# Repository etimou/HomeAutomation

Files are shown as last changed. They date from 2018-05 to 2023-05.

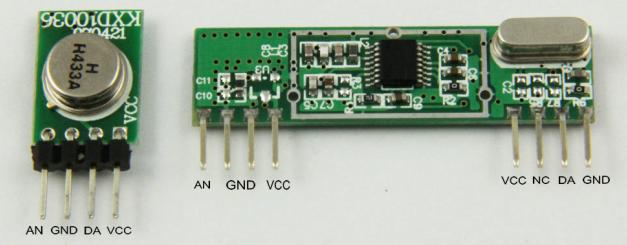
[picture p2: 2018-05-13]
hardware/rfbase/RFmodule_pinout2.jpg

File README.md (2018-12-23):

# HomeAutomation

Installation on Raspberrypi
---------------------------

1. git clone https://github.com/etimou/HomeAutomation
2. sudo apt-get install python-serial lighttpd
3. sudo cp /etc/lighttpd/lighttpd.conf /etc/lighttpd/lighttpd.conf.sav
4. sudo nano /etc/lighttpd/lighttpd.conf
   replace "/var/www/html" by "/home/pi/HomeAutomation/software/raspberrypi/www"
   add "mod_cgi" in the server.modules section

   add
   cgi.assign                 = ( ".pl"  => "/usr/bin/perl",
                               ".cgi" => "/usr/bin/perl",
                               ".rb"  => "/usr/bin/ruby",
                               ".erb" => "/usr/bin/eruby",
                               ".py"  => "/usr/bin/python",
                               ".php" => "/usr/bin/php-cgi" )
  change port from 80 to 8181

5. sudo service lighttpd restart

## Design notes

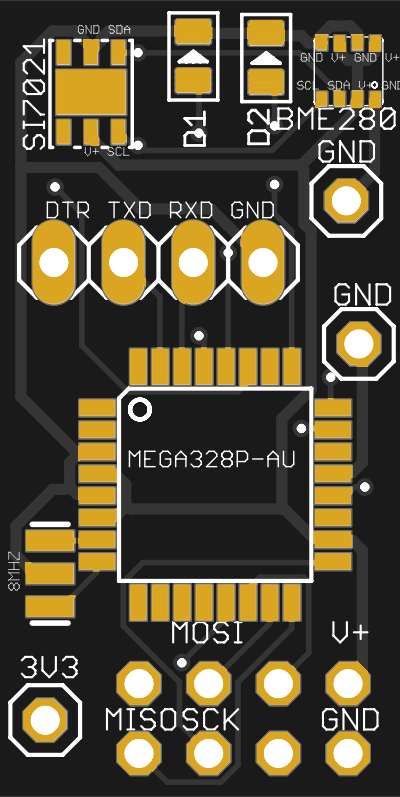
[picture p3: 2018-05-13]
hardware/rfsensor/top.svg.s.png

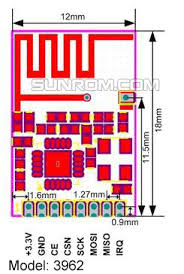
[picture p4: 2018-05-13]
hardware/rfsensor/index.jpeg

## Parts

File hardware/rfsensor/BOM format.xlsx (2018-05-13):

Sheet: PCB Manufacturing Specification
For PCB Manufacturing, would you please tell us the pcb specifications that you want?
You can refer to our webshop:(http://smart-prototyping.com/PCB-Prototyping.html)
Quantity:
Max X-Dimension (cm):
Max Y-Dimension (cm):
Layers:
PCB Thickness (mm):
Copper Thickness:
Surface Finish:
Solder Mask Color:
E-Test Pass:
Solder Paste Stencil:
Separated Sub-Boards:
Lead Time:

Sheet: Please fill in this format
 | BOM quantity (Required) |  | PCB/Project Name
 | Part Identification |  |  |  |  |  |  |  | Customer Information |  | Quantity
# | Part ID / Reference (Required) | Manufacturer | Part / Order Number (Required) | Description | Value (Required) | Package (Required) | THT (y/n) | Pins / Pads | Source/Link/ Datasheet/Note | Source / Target Price | Quantity per BOM (Required)

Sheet: Reference
 | BOM quantity | 10 |  | PCB/Project Name | Main Control V1.0
 | Part Identification |  |  |  |  |  |  |  | Customer Information |  | Quantity
# | Part ID / Reference | Manufacturer | Part / Order Number | Description | Value | Package | THT (y/n) | Pins / Pads | Source/Link/ Datasheet/Note | Source / Target Price | Quantity per BOM
1 | C1, C2, C3, C4, C5, C7, C8, C9, C10, C11, C12, C13, C14, C15, C16, C17 | Samsung | CL10B104KB8NNNC | Capacitor SMD Cer 100nF 10% 50V X7R 0603 | 100nF | 0603 | n | 2 | 478-5052-1-ND |  | 16
2 | C6 | Samsung | CL10A105K08NNNC | Capacitor SMD Cer 1uF 10% 16V X5R 0603 | 1uF | 0603 | n | 1 | 445-1604-1-ND |  | 1
3 | D3, D4, D5 | Kingbright | APT1608SURCK | LED 0603 SMD Hyper Red 630nm 220mcd 20mA | LED_SMD_Red_0603_220mcd |  | n | 2 | 754-1123-1-ND |  | 4
4 | D1 | Lite-On Inc | LTL-4231N | Trigger LED | LED THT |  | y | 2 | 160-1142-ND |  | 1
5 | D4 | Lite-On Inc | LTL-4221N | Power LED | LED THT |  | y | 2 | 160-1139-ND |  | 1
6 | D2 | Kingbright | APT1608CGCK | LED 0603 SMD Green 570nm 50mcd 20mA | LED_SMD_Green_0603_570nm |  | n | 2 | 754-1116-1-ND |  | 1
7 | D5 | ON Semiconductor | BAT54T1G | Schottky Barrier Diode, 2-Pin SOD-123, Tape and Reel | BAT54T1 |  | n | 2 | BAT54T1GOSCT-ND |  | 1
8 | D6 | Micro Commercial Co | BZT52C5V1-TP | Diode Zener SMD 5.1V 0.5W SOD-123 | DIODE_ZENER_4.7V_500mW |  | n | 2 | BZT52C5V1-TPMSCT-ND |  | 1
9 | H1 |  |  | Male Header, 2-Pin, straight, 2.54mm pitch | Header 2 |  | y | 2 | 455-1749-1-ND |  | 1
10 | ICSP1, J4 |  |  | Male Header, 3-Pin, Dual row, straight, 2.54mm pitch | Header 3X2 |  | y | 6 | 952-2092-ND |  | 2
11 | J1, J3, J5 | CUI Inc | SJ-2524-SMT-TR | 2.5mm Audio jack | SJ-2524-SMT |  | n | 4 | CP-2524SJTR-ND |  | 3
12 | J2 | JAE Electronics | DX4R005HJ5R2000 | Connector SMD USB Micro Type B middle mount | USB_Micro_TypeB |  | n | 9 | 670-2674-1-ND |  | 1

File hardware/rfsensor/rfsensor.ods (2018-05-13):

Id | Designator | Package | Quantity | Designation | Supplier and ref
1 | J4 |  | not mounted
2 | C1 | C_0603 | 1 | 10nF
3 | C2,C4,C5,C6 | C_0603 | 4 | 0.1uF
4 | C3,C7 | SMD-1206_Pol | 2 | 10uF
5 | D1 | LED_0603 | 1 | Green
6 |  |  | not mounted
7 |  |  | not mounted
8 | JP1 | Pin_Header_Straight_1x06_Pitch2.54mm | not mounted | CONN_01X06
9 | Q1 | Resonator_smd | 1 | 8MHz Ceramic Resonator Built in Capacitor Surface Mount | Murata Electronics North America
10 | R1 | R_0603 | 1 | 1M
11 | R2 | R_0603 | 1 | 330
12 | R3 | R_0603 | 1 | 10k
13 | R4,R5 | R_0603 | 2 | R
14 |  |  | not mounted
15 | U2 | TQFP-32_7x7mm_Pitch0.8mm | 1 | ATMEGA328P-AU | Microchip Technology
16 | U1 | si7021 | 1 | Si7021-A20 | SILICON LABS
17 | J5 |  | not mounted

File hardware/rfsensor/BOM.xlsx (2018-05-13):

 | Repere topographique | Quantite | Description | Fabricant | Reference (fabricant) | SKU (référence RS / Farnell / DigiKey / Mouser) | Fournisseur (RS / FA / DK / MO)
Exemple 1 : | C1,C2,C4,C5,C6 | 5 |  |  | C0603C104M4RACTU
 | U2 |  |  |  | ATMEGA328P-AUR
 | Q1 |  |  |  | CSTCE8M00G55-R0 |  | FA
 | Mode d'emploi : | Bien lire avant …..
 | L'ordre des colonnes n'a pas d'importance, seul les titres ont une importance
 | Les titres de colonne doivent être conservés (Repere, Quantite, Description, Fabricant, Reference, SKU)
 | La liste de composants doit commencer sur la deuxième ligne (Ligne '2')
 | Les répère topographique doivent être séparés par des virgules et/ou espace ; Attention, le système ne contrôle pas les doublons sur les repères topographiques
 | La quantité doit correspondre au nombre de repères topographiques
 | Si une description est nécessaire, il faut séparer ses caractéristiques par des espaces
 | La référence est prioritaire sur la description et ne doit contenir aucun espace (mais vous pouvez quand même renseigner la description, cela vous aidera à vérifier la recherche)
 | Le SKU est prioritaire sur la description et la référence fabricant (mais vous pouvez quand même renseigner ces informations, cela vous aidera à vérifier la recherche)
 | Un SKU doit être accompagné du fournisseur (RS / FA / DK / MO)
 | ATTENTION:
 | les informations "Référence / SKU" peuvent être informés en "ET / OU"
 | Par contre, si vous informez "SKU" qui est prioritaire, en fonction de la référence du fournisseur choisi (dispo ou pas), les 3 autres distributeurs ne seront pas consultés.
 | Pour une recherche élargie, nous vous conseillons d'indiquer seulement la référence

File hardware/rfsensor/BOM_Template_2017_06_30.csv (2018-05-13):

Designator | Manufacturer Part Number | Quantity
C1,C2,C3,C4,C5 | RHA0J471MCN1GS | 5
A1,A4 | 318020010 | 2
D1 | CYBLE-014008-00 | 1

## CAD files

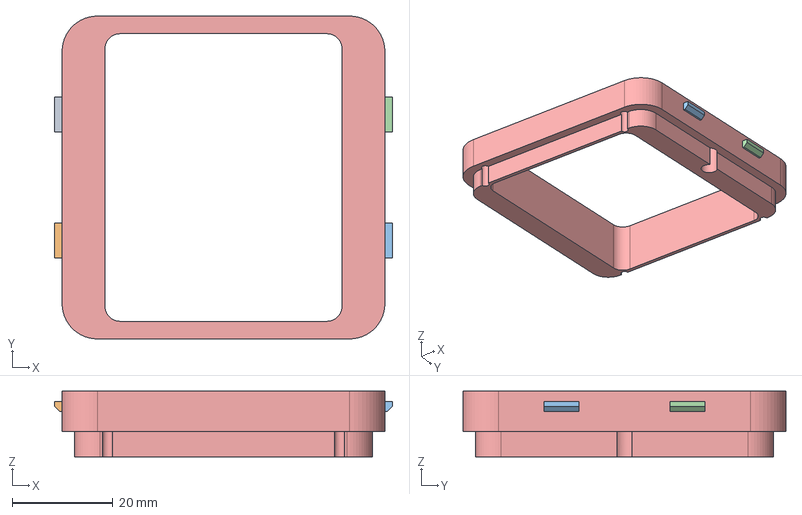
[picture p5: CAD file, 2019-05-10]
hardware/keypad/keypad3.fcstd
67.0 x 64.0 x 13.0 mm

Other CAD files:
hardware/rfsensor/gerber/rfsensor-F.Paste.dxf

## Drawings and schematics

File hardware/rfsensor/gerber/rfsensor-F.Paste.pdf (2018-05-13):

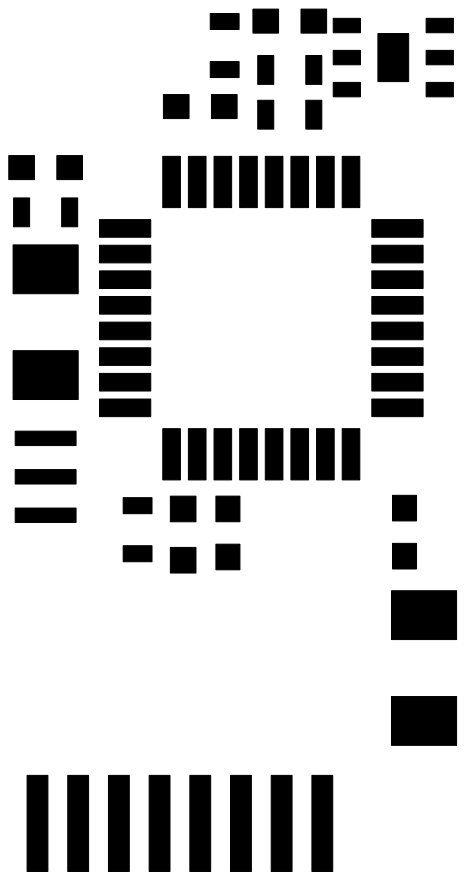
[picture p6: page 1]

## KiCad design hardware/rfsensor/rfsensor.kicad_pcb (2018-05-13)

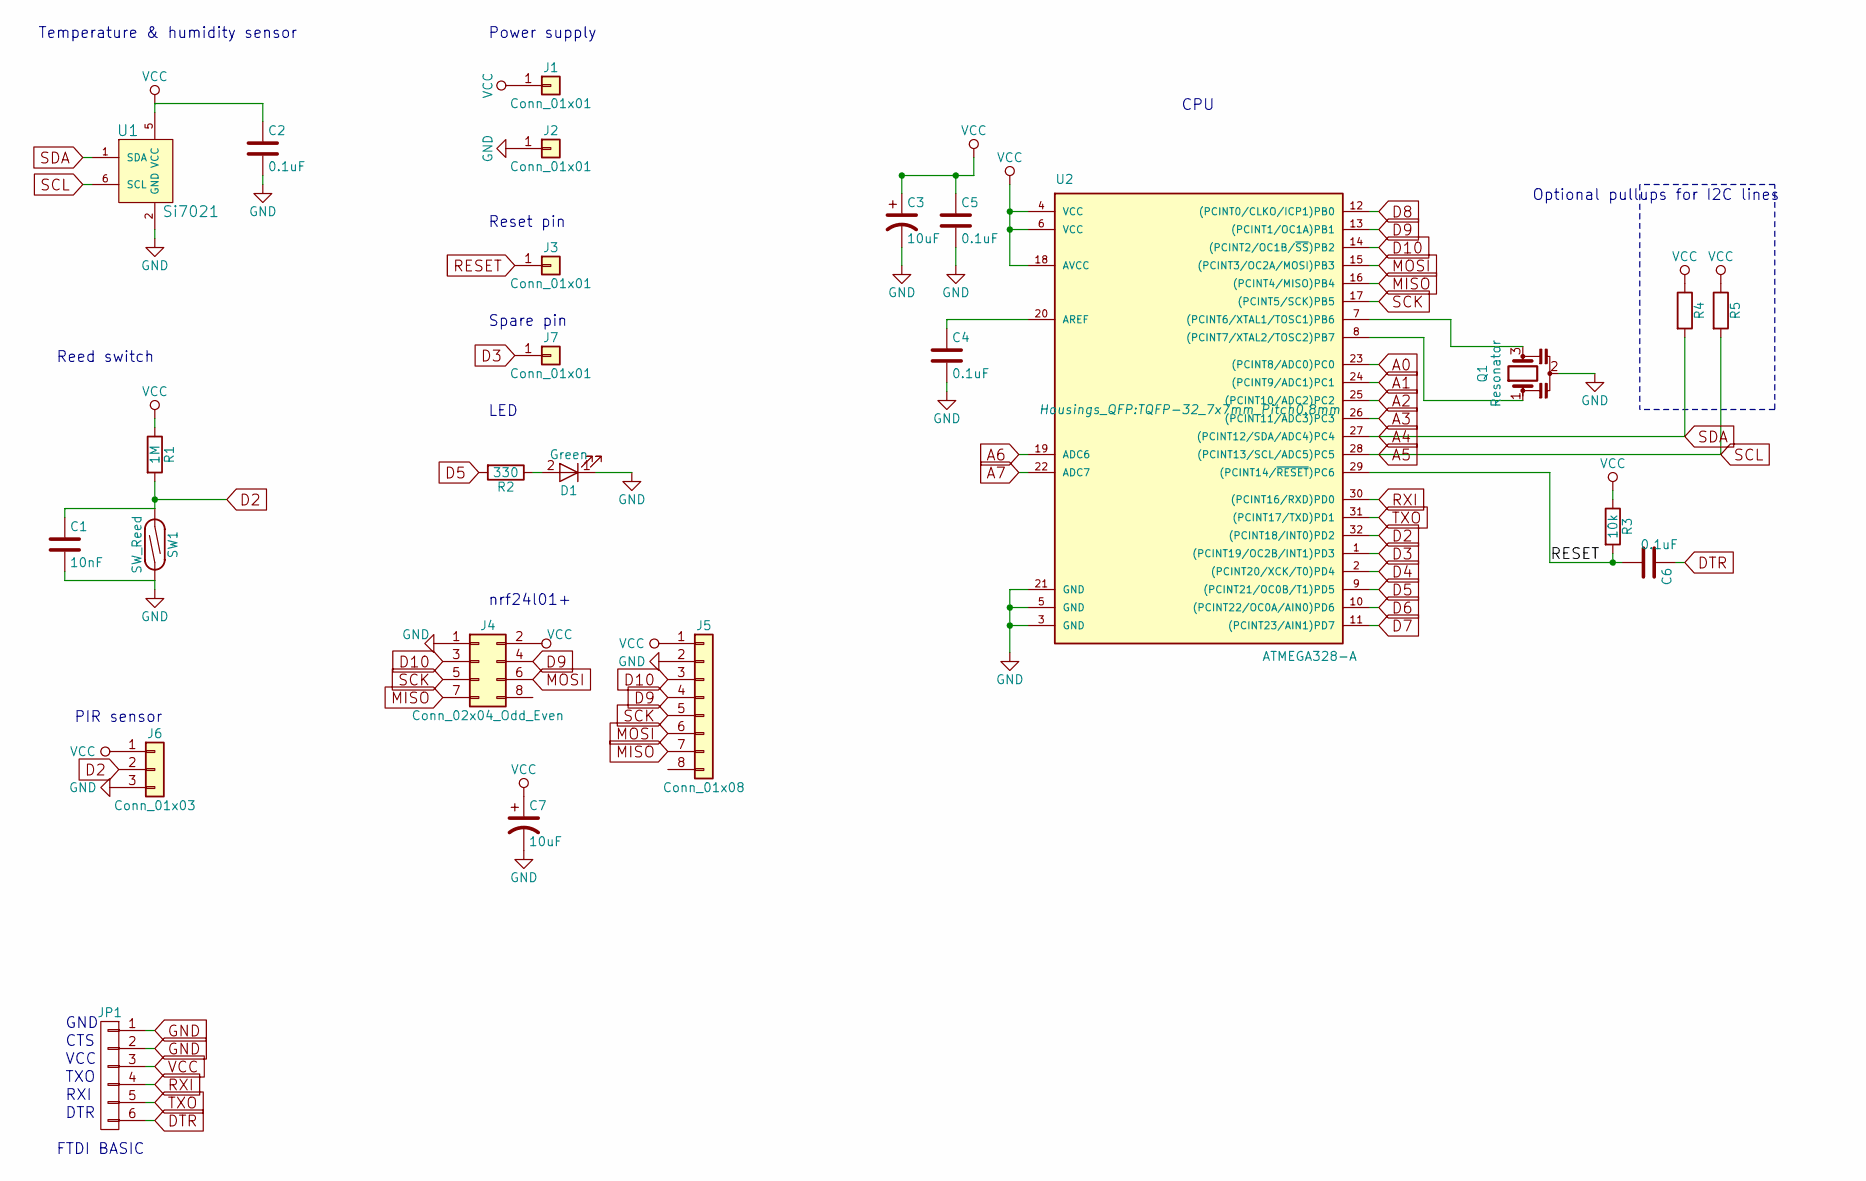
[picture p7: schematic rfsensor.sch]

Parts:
C1: 10nF; C_0603
C2, C4, C5, C6: 0.1uF; C_0603
C3, C7: 10uF; SMD-1206_Pol
D1: Green; LED_0603
J1, J2, J3, J7: Conn_01x01; Pin_Header_Straight_1x01_Pitch2.54mm
J4: Conn_02x04_Odd_Even; Pin_Header_Straight_2x04_Pitch2.54mm
J5: Conn_01x08; Pin_Header_Straight_1x08_Pitch1.27mm_SMD_Pin1Left
J6: Conn_01x03; Pin_Header_Straight_1x03_Pitch2.54mm
JP1: CONN_01X06; Pin_Header_Straight_1x06_Pitch2.54mm
Q1: Resonator; Resonator_smd
R1: 1M; R_0603
R2: 330; R_0603
R3: 10k; R_0603
R4, R5: R; R_0603
SW1: SW_Reed; reed
U1: Si7021; DFN-6-1EP_3x3mm_Pitch0.95mm
U2: ATMEGA328-A; TQFP-32_7x7mm_Pitch0.8mm

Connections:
A0: U2.23 ((PCINT8/ADC0)PC0)
A1: U2.24 ((PCINT9/ADC1)PC1)
A2: U2.25 ((PCINT10/ADC2)PC2)
A3: U2.26 ((PCINT11/ADC3)PC3)
A4: R4.2, U1.1 (SDA), U2.27 ((PCINT12/SDA/ADC4)PC4)
A5: R5.2, U1.6 (SCL), U2.28 ((PCINT13/SCL/ADC5)PC5)
A6: U2.19 (ADC6)
A7: U2.22 (ADC7)
D2: C1.1, J6.2, R1.2, SW1.1, U2.32 ((PCINT18/INT0)PD2)
D3: J7.1, U2.1 ((PCINT19/OC2B/INT1)PD3)
D4: U2.2 ((PCINT20/XCK/T0)PD4)
D5: R2.2, U2.9 ((PCINT21/OC0B/T1)PD5)
D6: U2.10 ((PCINT22/OC0A/AIN0)PD6)
D7: U2.11 ((PCINT23/AIN1)PD7)
D8: U2.12 ((PCINT0/CLKO/ICP1)PB0)
D9: J4.4, J5.4, U2.13 ((PCINT1/OC1A)PB1)
D10: J4.3, J5.3, U2.14 ((PCINT2/OC1B/~SS~)PB2)
DTR: C6.1, JP1.6
GND: C1.2, C2.2, C3.2, C4.2, C5.2, C7.2, D1.1 (K), J2.1, J4.1, J5.2, J6.3, JP1.1, JP1.2, Q1.2, SW1.2, U1.2 (GND), U2.3 (GND), U2.5 (GND), U2.21 (GND)
MISO: J4.7, J5.7, U2.16 ((PCINT4/MISO)PB4)
MOSI: J4.6, J5.6, U2.15 ((PCINT3/OC2A/MOSI)PB3)
unnamed: C4.1, U2.20 (AREF)
unnamed: D1.2 (A), R2.1
unnamed: Q1.1, U2.8 ((PCINT7/XTAL2/TOSC2)PB7)
unnamed: Q1.3, U2.7 ((PCINT6/XTAL1/TOSC1)PB6)
RESET: C6.2, J3.1, R3.2, U2.29 ((PCINT14/~RESET~)PC6)
RXI: JP1.4, U2.30 ((PCINT16/RXD)PD0)
SCK: J4.5, J5.5, U2.17 ((PCINT5/SCK)PB5)
TXO: JP1.5, U2.31 ((PCINT17/TXD)PD1)
VCC: C2.1, C3.1, C5.1, C7.1, J1.1, J4.2, J5.1, J6.1, JP1.3, R1.1, R3.1, R4.1, R5.1, U1.5 (VCC), U2.4 (VCC), U2.6 (VCC), U2.18 (AVCC)

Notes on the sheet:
Optional pullups for I2C lines
GND
CTS
VCC
TXO
RXI
DTR
FTDI BASIC
nrf24l01+
Power supply
Reset pin
Temperature & humidity sensor
Reed switch
CPU
LED
PIR sensor
Spare pin

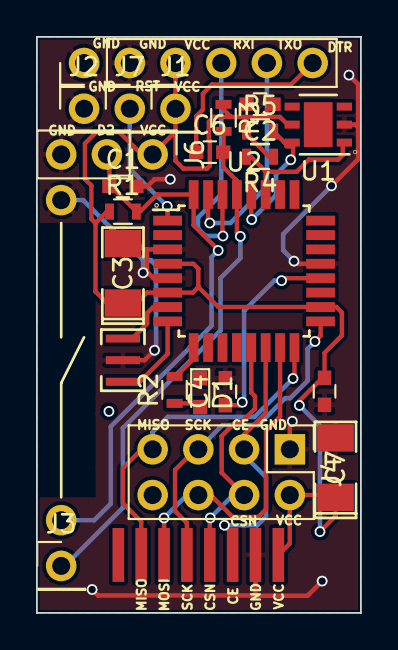
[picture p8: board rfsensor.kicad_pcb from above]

Board: 2 copper layers, 18.0 x 32.0 mm, 25 parts (0 on the bottom side), 20 nets.

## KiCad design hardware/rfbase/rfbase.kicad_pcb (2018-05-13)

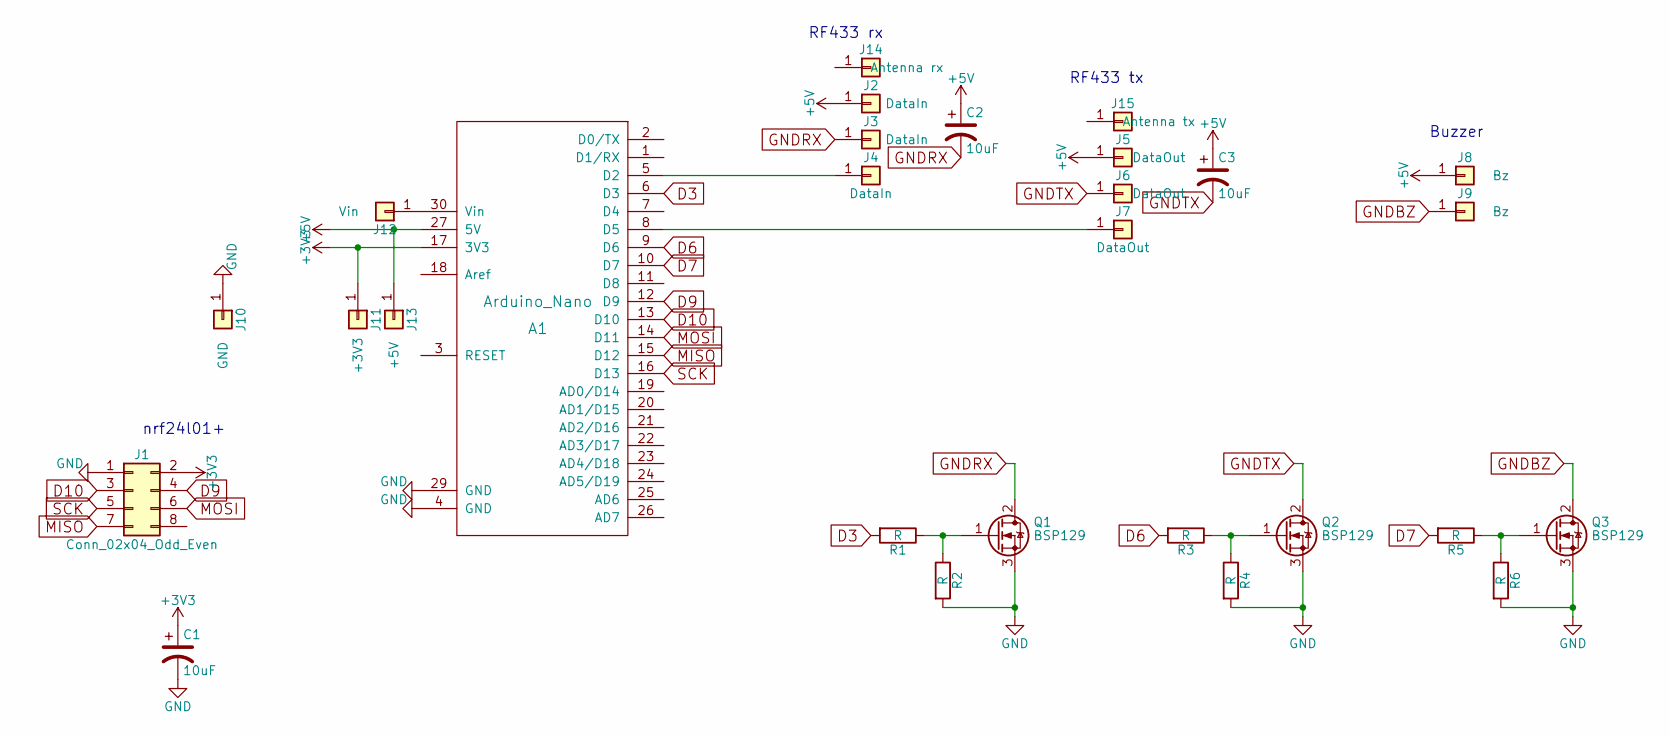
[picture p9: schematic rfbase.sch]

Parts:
A1: Arduino_Nano; arduino_nano
C1, C2, C3: 10uF; SMD-1206_Pol
J1: Conn_02x04_Odd_Even; Pin_Header_Straight_2x04_Pitch2.54mm
J2, J3, J4: DataIn; Pin_Header_Straight_1x01_Pitch2.54mm
J5, J6, J7: DataOut; Pin_Header_Straight_1x01_Pitch2.54mm
J8, J9: Bz; Pin_Header_Straight_1x01_Pitch2.54mm
J10: GND; Pin_Header_Straight_1x01_Pitch2.54mm
J11: +3V3; Pin_Header_Straight_1x01_Pitch2.54mm
J12: Vin; Pin_Header_Straight_1x01_Pitch2.54mm
J13: +5V; Pin_Header_Straight_1x01_Pitch2.54mm
J14: Antenna rx; Pin_Header_Straight_1x01_Pitch2.54mm
J15: Antenna tx; Pin_Header_Straight_1x01_Pitch2.54mm
Q1, Q2, Q3: BSP129; SOT-223-3Lead_TabPin2
R1, R2, R3, R4, R5, R6: R; R_0603

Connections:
+3V3: A1.17 (3V3), C1.1, J1.2, J11.1
+5V: A1.27 (5V), C2.1, C3.1, J2.1, J5.1, J8.1, J13.1
D3: A1.6 (D3), R1.2
D6: A1.9 (D6), R3.2
D7: A1.10 (D7), R5.2
D9: A1.12 (D9), J1.4
D10: A1.13 (D10), J1.3
GND: A1.4 (GND), A1.29 (GND), C1.2, J1.1, J10.1, Q1.3 (S), Q2.3 (S), Q3.3 (S), R2.2, R4.2, R6.2
GNDBZ: J9.1, Q3.2 (D)
GNDRX: C2.2, J3.1, Q1.2 (D)
GNDTX: C3.2, J6.1, Q2.2 (D)
MISO: A1.15 (D12), J1.7
MOSI: A1.14 (D11), J1.6
unnamed: A1.5 (D2), J4.1
unnamed: A1.8 (D5), J7.1
unnamed: A1.30 (Vin), J12.1
unnamed: Q1.1 (G), R1.1, R2.1
unnamed: Q2.1 (G), R3.1, R4.1
unnamed: Q3.1 (G), R5.1, R6.1
SCK: A1.16 (D13), J1.5

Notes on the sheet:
nrf24l01+
RF433 rx
RF433 tx
Buzzer

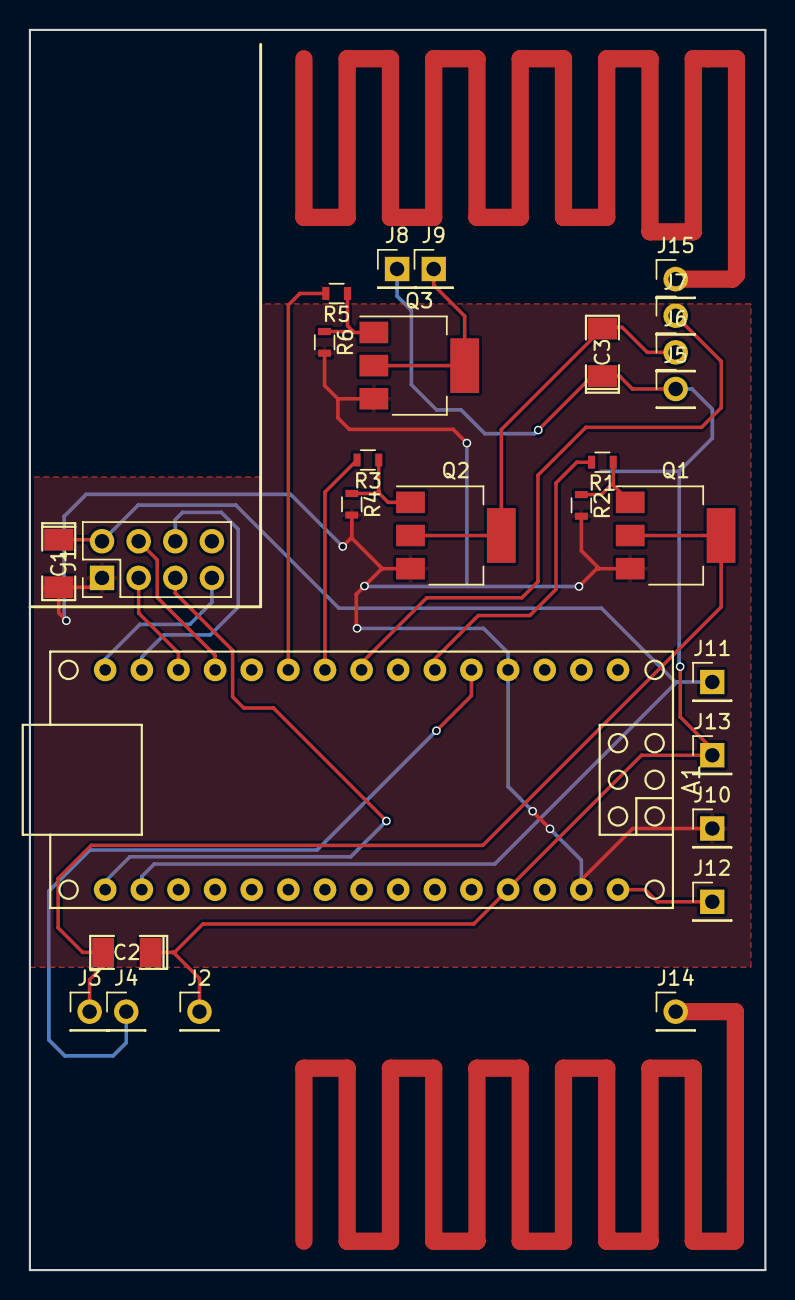
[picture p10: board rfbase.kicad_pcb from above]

Board: 2 copper layers, 51.0 x 86.0 mm, 28 parts (0 on the bottom side), 20 nets.

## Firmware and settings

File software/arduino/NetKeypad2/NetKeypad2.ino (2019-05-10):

// Wake from deep sleep with a keypress demonstration

// Author: Nick Gammon
// Date: 18th November 2012

#include "Keypad2.h"
#include <avr/sleep.h>
#include <avr/power.h>
#include <SPI.h>
#include <RF24.h>
#include <EEPROM.h>

const byte ROWS = 4;
const byte COLS = 3; 

char keys[ROWS][COLS] = 
  {
    {'1', '2', '3'},
    {'4', '5', '6'},
    {'7', '8', '9'},
    {'*', '0', '#'},
  };

byte rowPins[ROWS] = {6, 7, 8, 9}; //connect to the row pinouts of the keypad
byte colPins[COLS] = {2, 3, 4}; //connect to the column pinouts of the keypad
bool state;

/*
arduino keypad 
6 2
7 7
8 6
9 4

2 3
3 1
4 5
*/


/*                           NRF24L01      
 * NC----------------------IRQ 8 7 MISO---------------12
 * 11---------------------MOSI 6 5 SCK----------------13
 *  5-----------------------CS 4 3 CE-----------------10
 *VCC----------------------VCC 2 1 GND----------------GND
 */

char secretCodeON[4] = {'7', '5', '1', '#'};
char secretCodeOFF[4] = {'7', '5', '0', '#'};
char enteredCode[4] = {'0', '0', '0', '0'};
  
// number of items in an array
#define NUMITEMS(arg) ((unsigned int) (sizeof (arg) / sizeof (arg [0])))

const byte ledPin = A0;
unsigned long calib=0;
byte sensorID=0;
byte voltage=0;

  // Create the Keypad
Keypad kpd = Keypad( makeKeymap(keys), rowPins, colPins, ROWS, COLS );


/* Set up nRF24L01 radio on SPI bus plus pins 10 & 9 */
RF24 radio(10,5);
byte addresses[6] = "1Node";

/*

Pin change interrupts.

Pin                  Mask / Flag / Enable

D0    PCINT16 (PCMSK2 / PCIF2 / PCIE2)
D1    PCINT17 (PCMSK2 / PCIF2 / PCIE2)
D2    PCINT18 (PCMSK2 / PCIF2 / PCIE2)
D3    PCINT19 (PCMSK2 / PCIF2 / PCIE2)
D4    PCINT20 (PCMSK2 / PCIF2 / PCIE2)
D5    PCINT21 (PCMSK2 / PCIF2 / PCIE2)
D6    PCINT22 (PCMSK2 / PCIF2 / PCIE2)
D7    PCINT23 (PCMSK2 / PCIF2 / PCIE2)
D8    PCINT0 (PCMSK0 / PCIF0 / PCIE0)
D9    PCINT1 (PCMSK0 / PCIF0 / PCIE0)
D10   PCINT2 (PCMSK0 / PCIF0 / PCIE0)
D11   PCINT3 (PCMSK0 / PCIF0 / PCIE0)
D12   PCINT4 (PCMSK0 / PCIF0 / PCIE0)
D13   PCINT5 (PCMSK0 / PCIF0 / PCIE0)
A0    PCINT8 (PCMSK1 / PCIF1 / PCIE1)
A1    PCINT9 (PCMSK1 / PCIF1 / PCIE1)
A2    PCINT10 (PCMSK1 / PCIF1 / PCIE1)
A3    PCINT11 (PCMSK1 / PCIF1 / PCIE1)
A4    PCINT12 (PCMSK1 / PCIF1 / PCIE1)
A5    PCINT13 (PCMSK1 / PCIF1 / PCIE1)

*/

// turn off interrupts until we are ready
ISR (PCINT0_vect)
  {
  PCICR = 0;  // cancel pin change interrupts
  } // end of ISR (PCINT0_vect)

ISR (PCINT1_vect)
  {
  PCICR = 0;  // cancel pin change interrupts
  } // end of ISR (PCINT1_vect)

ISR (PCINT2_vect)
  {
  PCICR = 0;  // cancel pin change interrupts
  } // end of ISR (PCINT2_vect)

byte readVcc() {
  // Read 1.1V reference against AVcc
  // set the reference to Vcc and the measurement to the internal 1.1V reference
  #if defined(__AVR_ATmega32U4__) || defined(__AVR_ATmega1280__) || defined(__AVR_ATmega2560__)
    ADMUX = _BV(REFS0) | _BV(MUX4) | _BV(MUX3) | _BV(MUX2) | _BV(MUX1);
  #elif defined (__AVR_ATtiny24__) || defined(__AVR_ATtiny44__) || defined(__AVR_ATtiny84__)
    ADMUX = _BV(MUX5) | _BV(MUX0);
  #elif defined (__AVR_ATtiny25__) || defined(__AVR_ATtiny45__) || defined(__AVR_ATtiny85__)
    ADMUX = _BV(MUX3) | _BV(MUX2);
  #else
    ADMUX = _BV(REFS0) | _BV(MUX3) | _BV(MUX2) | _BV(MUX1);
  #endif  

  delay(70); // Wait for Vref to settle
  ADCSRA |= _BV(ADSC); // Start conversion
  while (bit_is_set(ADCSRA,ADSC)); // measuring

  uint8_t low  = ADCL; // must read ADCL first - it then locks ADCH  
  uint8_t high = ADCH; // unlocks both

  long result = (high<<8) | low;

  result = calib / result; // Calculate Vcc (in mV); 1125300 = 1.1*1023*1000 //ok for proto w/ intermediate PCB
  
  //from millivolt to percentage
  result=map(result, 3000, 3400, 0, 100); //3.0V->0% 3.4V->100%

  if (result >100) return 100;
  if (result <0) return 0;
  return (byte)result; // Vcc in millivolts

/*
While the large tolerance of the internal 1.1 volt reference greatly limits the accuracy of 
this measurement, for individual projects we can compensate for greater accuracy. To do so, 
simply measure your Vcc with a voltmeter and with our readVcc() function. Then, replace the 
constant 1125300L with a new constant:
scale_constant = internal1.1Ref * 1023 * 1000
where
internal1.1Ref = 1.1 * Vcc1 (per voltmeter) / Vcc2 (per readVcc() function)
This calibrated value will be good for the AVR chip measured only, and may be subject to temperature variation. Feel free to experiment with your own measurements.
*/
}

void radioSetup(){
  radio.begin();

  // Set the PA Level low to prevent power supply related issues since this is a
  // getting_started sketch, and the likelihood of close proximity of the devices. RF24_PA_MAX is default.
  //radio.setPALevel(RF24_PA_LOW);
  
  radio.setPALevel(RF24_PA_MAX);
  radio.setDataRate(RF24_250KBPS);
  radio.setChannel(108);
  //radio.setRetries(5,15);
  radio.setPayloadSize(4);
  
  // Open a writing and reading pipe on each radio, with opposite addresses
  radio.openWritingPipe(addresses);
  radio.stopListening();
  radio.powerDown();
}
void sendRadioData(){
    //Power up the radio
    radio.powerUp();
  
    byte data_to_send[4];
    data_to_send[0]= sensorID;
    data_to_send[1]= state;
    data_to_send[2]= voltage;
    data_to_send[3]= 0;

    radio.write( data_to_send, 4);

    //Power off the radio    
    radio.powerDown();
  
}

void setup ()
{
  pinMode (ledPin, OUTPUT);

  //radio setup
  radioSetup();

  // pin change interrupt masks (see above list)
  PCMSK2 |= bit (PCINT22);   // pin 6
  PCMSK2 |= bit (PCINT23);   // pin 7
  PCMSK0 |= bit (PCINT0);    // pin 8
  PCMSK0 |= bit (PCINT1);    // pin 9



  Serial.begin(57600);
  // get the device ID from EEPROM address 0
  //EEPROM.write(0, 12);
  sensorID = EEPROM.read(0);
  Serial.print("Device ID=");
  Serial.println(sensorID);

  //get the calibration value
  //EEPROM.put(1,1108835L);
  EEPROM.get(1, calib);
  Serial.print("Calibration value=");
  Serial.println(calib);

  Serial.println("Initialisation complete.");

  // calibration and Id
  char readchar[5];
  char nchar=0;
  while (millis()<5000){
    while (Serial.available()>0){
      if (nchar<=4){
        readchar[nchar]=Serial.read();
        nchar++;
      }
      if (nchar==5){
        if (readchar[0]=='s' && readchar[3]=='c'){
          char newID = (readchar[1]-48)*10+readchar[2]-48;
          if (newID){
            saveIdToEEPROM((readchar[1]-48)*10+readchar[2]-48);
          }
          if ((readchar[4]-48)==1){
            calibrationVoltage(3300);
          }
        }
        else{
          Serial.print("Wrong command...");
        }
        Serial.println("Starting main program");

        delay(50);
        while (Serial.available()>0){Serial.read();}
        
        return;
      }
    } 
  }
  Serial.println("No command received... Starting main program");
  Serial.end();

  delay(100);


}  // end of setup

// set pins as keypad library expects them
// or call: kpd.initializePins ();
//    however in the library I have that is a private method

void reconfigurePins ()
  {
  byte i;
  
  // go back to all pins as per the keypad library
  
  for (i = 0; i < NUMITEMS (colPins); i++)
    {
    pinMode (colPins [i], OUTPUT);
    digitalWrite (colPins [i], HIGH); 
    }  // end of for each column 

  for (i = 0; i < NUMITEMS (rowPins); i++)
    {
    pinMode (rowPins [i], INPUT_PULLUP);
    }   // end of for each row

  }  // end of reconfigurePins

void goToSleep ()
  {
  byte i;
   
  // set up to detect a keypress
  for (i = 0; i < NUMITEMS (colPins); i++)
    {
    pinMode (colPins [i], OUTPUT);
    digitalWrite (colPins [i], LOW);   // columns low
    }  // end of for each column

  for (i = 0; i < NUMITEMS (rowPins); i++)
    {
    pinMode (rowPins [i], INPUT_PULLUP);
    }  // end of for each row
    
   // now check no pins pressed (otherwise we wake on a key release)
   for (i = 0; i < NUMITEMS (rowPins); i++)
    {
    if (digitalRead (rowPins [i]) == LOW)
       {
       reconfigurePins ();
       return; 
       } // end of a pin pressed
    }  // end of for each row
  
  // overcome any debounce delays built into the keypad library
  delay (50);
  
  // at this point, pressing a key should connect the high in the row to the 
  // to the low in the column and trigger a pin change
  
  set_sleep_mode (SLEEP_MODE_PWR_DOWN);  
  sleep_enable();

  byte old_ADCSRA = ADCSRA;
  // disable ADC to save power
  ADCSRA = 0;  

  power_all_disable ();  // turn off various modules
   
  PCIFR  |= bit (PCIF0) | bit (PCIF1) | bit (PCIF2);   // clear any outstanding interrupts
  PCICR  |= bit (PCIE0) | bit (PCIE1) | bit (PCIE2);   // enable pin change interrupts
   
  // turn off brown-out enable in software
  MCUCR = bit (BODS) | bit (BODSE);
  MCUCR = bit (BODS); 
  sleep_cpu ();  
 
  // cancel sleep as a precaution
  sleep_disable();
  power_all_enable ();   // enable modules again
  ADCSRA = old_ADCSRA;   // re-enable ADC conversion
  
  // put keypad pins back how they are expected to be
  reconfigurePins ();
    
  }  // end of goToSleep
  
void loop () 
  {
   
   byte key =  kpd.getKey();
   if (!key)
     {
     // no key pressed? go to sleep
     goToSleep ();
     return;
     }


  // confirmation we woke - flash LED number of times
  // for the appropriate pin (eg. pin 1: one time) 
  /*
  for (byte i = 0; i < (key - '0'); i++)
    {
    digitalWrite (ledPin, HIGH);
    delay (500); 
    digitalWrite (ledPin, LOW);
    delay (500); 
    } // end of for loop
  */
  digitalWrite (ledPin, HIGH);
  delay (300); 
  digitalWrite (ledPin, LOW);
  
  enteredCode[0]= enteredCode[1];
  enteredCode[1]= enteredCode[2];
  enteredCode[2]= enteredCode[3];
  enteredCode[3] = key;

  if ((enteredCode[0]==secretCodeON[0])&&(enteredCode[1]==secretCodeON[1])&&(enteredCode[2]==secretCodeON[2])&&(enteredCode[3]==secretCodeON[3]))
  {
    state = 1;
    voltage = readVcc();
    
    sendRadioData();
    
    for (byte i = 0; i < 10; i++)
    {
      digitalWrite (ledPin, HIGH);
      delay (100); 
      digitalWrite (ledPin, LOW);
      delay (100); 
    }


      
  }
  if ((enteredCode[0]==secretCodeOFF[0])&&(enteredCode[1]==secretCodeOFF[1])&&(enteredCode[2]==secretCodeOFF[2])&&(enteredCode[3]==secretCodeOFF[3]))
  {
    state = 0;
    voltage = readVcc();
    
    sendRadioData();
    
    digitalWrite (ledPin, HIGH);
    delay (3000); 
    digitalWrite (ledPin, LOW);
    
  }
  
 } // end of loop


 void saveIdToEEPROM(byte IdValue){
  sensorID = IdValue;
  Serial.print("Storing sensor ID value in EEPROM: ");
  Serial.println(IdValue);
  EEPROM.write(0, IdValue);
}
void calibrationVoltage(int milliVolt){
  // Read 1.1V reference against AVcc
  // set the reference to Vcc and the measurement to the internal 1.1V reference
  #if defined(__AVR_ATmega32U4__) || defined(__AVR_ATmega1280__) || defined(__AVR_ATmega2560__)
    ADMUX = _BV(REFS0) | _BV(MUX4) | _BV(MUX3) | _BV(MUX2) | _BV(MUX1);
  #elif defined (__AVR_ATtiny24__) || defined(__AVR_ATtiny44__) || defined(__AVR_ATtiny84__)
    ADMUX = _BV(MUX5) | _BV(MUX0);
  #elif defined (__AVR_ATtiny25__) || defined(__AVR_ATtiny45__) || defined(__AVR_ATtiny85__)
    ADMUX = _BV(MUX3) | _BV(MUX2);
  #else
    ADMUX = _BV(REFS0) | _BV(MUX3) | _BV(MUX2) | _BV(MUX1);
  #endif  

  delay(70); // Wait for Vref to settle
  ADCSRA |= _BV(ADSC); // Start conversion
  while (bit_is_set(ADCSRA,ADSC)); // measuring

  uint8_t low  = ADCL; // must read ADCL first - it then locks ADCH  
  uint8_t high = ADCH; // unlocks both

  long result = (high<<8) | low;

  result = 1125300L / result; // Calculate Vcc (in mV); 1125300 = 1.1*1023*1000

  Serial.print("Measured ");
  Serial.print(result/1000.0);
  Serial.println("V");


  if ((result<3000) || (result>4000)){
    Serial.println("Voltage not in acceptable range for 3.3V calibration");
    return;
  }
  
  
  calib = (unsigned long)(1125300L * float(milliVolt) / result); //write in float(...) the value you measure with a multimeter

  Serial.print("Storing calibration value in EEPROM: ");
  Serial.println(calib);
  EEPROM.put(1,calib);
}

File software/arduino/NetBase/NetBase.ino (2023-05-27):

#include <EEPROM.h>

const byte numChars = 128;
char receivedChars[numChars];   // an array to store the received data
char tempChars[numChars];        // temporary array for use when parsing
byte frame[7]; // frame for Somfy protocol
unsigned char msg_counter = 0;

unsigned char protocolName = 0; //data to be parsed
unsigned long deviceAddress = 0;
unsigned char buttonNumber = 0;
unsigned char actionCommand = 0;

bool PIRstatus = 0;
bool edgeDetected = 0;
unsigned long  edgeDetectedTime = 0;

#define PROTOCOL_SOMFY 1
#define PROTOCOL_HOMEEASY 2
#define PROTOCOL_NEWKAKU 3
#define PROTOCOL_PING 4
#define UP 0x2
#define STOP 0x1
#define DOWN 0x4
#define PROG 0x8
#define ON 0x3
#define OFF 0x5

#define PIN_TXS 4
#define PIN_TX 5
#define PIN_ALARM 7
#define PIN_PIR 6
#define RETRIES 5
#define EEPROM_ADDRESS 0
#define REMOTE 0x121300    //<-- Change it!
#define SYMBOL 640



void setup() {
  Serial.begin(57600);

  pinMode(PIN_TX, OUTPUT);
  digitalWrite(PIN_TX, LOW);
  pinMode(PIN_TXS, OUTPUT);
  digitalWrite(PIN_TXS, LOW);
  pinMode(PIN_ALARM, OUTPUT);
  digitalWrite(PIN_ALARM, LOW);
  pinMode(PIN_PIR, INPUT_PULLUP);

  // Welcome message
  Serial.println("20;00;Etimou RadioFrequencyLink - RFLink Gateway Clone V1.0;");
}

void loop() {

  /*main loop, waiting for events*/

  if (recvWithEndMarker()) { //event from serial
    if (parseData() != -1) {
      processCommand();
    }
  }

  processLocal();

}

bool recvWithEndMarker() {
  static byte ndx = 0;
  char rc;
  boolean newData = false;

  while (Serial.available() > 0) {
    rc = Serial.read();

    if (rc != '\n' && rc != '\r') {
      receivedChars[ndx] = rc;
      ndx++;
      if (ndx >= numChars) {
        ndx = numChars - 1;
      }
    }
    else {
      if (ndx > 0) {
        receivedChars[ndx] = '\0'; // terminate the string
        ndx = 0;
        newData = true;
        //Serial.println(receivedChars);
      }
    }
  }
  return newData;
}

int parseData() {

  protocolName = 0; //set default values before start
  deviceAddress = 0;
  buttonNumber = 0;
  actionCommand = 0;

  strcpy(tempChars, receivedChars); //copy the received string

  char * strtokIndx; // this is used by strtok() as an index

  strtokIndx = strstr(tempChars, "10");
  if (strlen(strtokIndx) <= 2) {
    return -1;
  }


  strtokIndx = strtok(strtokIndx, ";");     // get the first part
  if (strtokIndx == NULL)
    return -1;


  strtokIndx = strtok(NULL, ";");
  if (strtokIndx == NULL)
    return -1;


  if (!strcmp(strtokIndx, "RTS")) protocolName = PROTOCOL_SOMFY;
  else if (!strcmp(strtokIndx, "X10")) protocolName = PROTOCOL_SOMFY;
  else if (!strcmp(strtokIndx, "HomeEasy")) protocolName = PROTOCOL_HOMEEASY;
  else if (!strcmp(strtokIndx, "NewKaku")) protocolName = PROTOCOL_NEWKAKU;
  else if (!strcmp(strtokIndx, "Kaku")) protocolName = PROTOCOL_NEWKAKU;
  else if (!strcmp(strtokIndx, "PING")) {
    protocolName = PROTOCOL_PING;
    return 0;
  }
  else return -1;

  strtokIndx = strtok(NULL, ";");
  if (strtokIndx == NULL)
    return -1;

  deviceAddress = strtol(strtokIndx, NULL, 16);
  if (deviceAddress == 0)
    return -1;
  if (protocolName == PROTOCOL_HOMEEASY) {
    deviceAddress = deviceAddress & 0x00FFFFFF;
  }

  strtokIndx = strtok(NULL, ";");
  if (strtokIndx == NULL)
    return -1;

  buttonNumber = (int)strtol(strtokIndx, NULL, 16) - 1;

  strtokIndx = strtok(NULL, ";");
  if (strtokIndx == NULL)
    return -1;


  if (!strcmp(strtokIndx, "ON")) actionCommand = ON;
  else if (!strcmp(strtokIndx, "OFF")) actionCommand = OFF;
  else if (!strcmp(strtokIndx, "UP")) actionCommand = UP;
  else if (!strcmp(strtokIndx, "DOWN")) actionCommand = DOWN;
  else if (!strcmp(strtokIndx, "STOP")) actionCommand = STOP;
  else if (!strcmp(strtokIndx, "PROG")) actionCommand = PROG;
  else return -1;

  return 0;


}



void processCommand() {

  if (protocolName == PROTOCOL_HOMEEASY) {
    sendHomeEasy();
  }
  else if (protocolName == PROTOCOL_NEWKAKU) {
    if (deviceAddress == 0xFFFFFF) {
      digitalWrite(PIN_ALARM, actionCommand == ON);
    }
    else if (deviceAddress == 0xFFFFFE) {
      if (actionCommand == ON)
      {
        digitalWrite(PIN_ALARM, HIGH);
        delay(150);
        digitalWrite(PIN_ALARM, LOW);
        delay(300);
        digitalWrite(PIN_ALARM, HIGH);
        delay(150);
        digitalWrite(PIN_ALARM, LOW);
      }
      else {
        digitalWrite(PIN_ALARM, HIGH);
        delay(150);
        digitalWrite(PIN_ALARM, LOW);
      }
    }
    else {
      if (actionCommand == ON) sendSimple433();
    }
  }
  else if (protocolName == PROTOCOL_SOMFY) {
    sendSomfy();
  }

  Serial.print("20;");
  Serial.print(msg_counter++, HEX);
  Serial.print(";OK;");
  Serial.println();
}

void sendSimple433()
{
  int dataLength = 24;
  for (int n = 0; n < RETRIES; n++)
  {
    digitalWrite(PIN_TX, HIGH);
    delayMicroseconds(510);
    digitalWrite(PIN_TX, LOW);
    delayMicroseconds(2040);


    for (int i = dataLength - 1; i >= 0; i--) {
      if (deviceAddress & (1L << i))
      {
        digitalWrite(PIN_TX, HIGH);
        delayMicroseconds(1020);
        digitalWrite(PIN_TX, LOW);
        delayMicroseconds(510);
      }
      else
      {
        digitalWrite(PIN_TX, HIGH);
        delayMicroseconds(510);
        digitalWrite(PIN_TX, LOW);
        delayMicroseconds(1020);
      }
    }
  }
}

void sendHomeEasyOne()
{
  digitalWrite(PIN_TX, HIGH);
  delayMicroseconds(275);
  digitalWrite(PIN_TX, LOW);
  delayMicroseconds(1225);
  digitalWrite(PIN_TX, HIGH);
  delayMicroseconds(275);
  digitalWrite(PIN_TX, LOW);
  delayMicroseconds(275);
}
void sendHomeEasyZero()
{
  digitalWrite(PIN_TX, HIGH);
  delayMicroseconds(275);
  digitalWrite(PIN_TX, LOW);
  delayMicroseconds(275);
  digitalWrite(PIN_TX, HIGH);
  delayMicroseconds(275);
  digitalWrite(PIN_TX, LOW);
  delayMicroseconds(1225);
}



void sendHomeEasy()
{
  for (int n = 0; n < RETRIES; n++)
  {
    digitalWrite(PIN_TX, HIGH);
    delayMicroseconds(275);
    digitalWrite(PIN_TX, LOW);
    delayMicroseconds(2675);

    //address
    for (int i = 25; i >= 0; i--) {
      if (deviceAddress & (1L << i)) sendHomeEasyOne();
      else sendHomeEasyZero();

    }
    //group flag, not managed
    sendHomeEasyZero();

    //command 0 or 1
    if (actionCommand == ON) sendHomeEasyOne();
    else sendHomeEasyZero();

    //device code
    for (int i = 3; i >= 0; i--) {
      if (buttonNumber & (1L << i)) sendHomeEasyOne();
      else sendHomeEasyZero();

    }
    //end
    digitalWrite(PIN_TX, HIGH);
    delayMicroseconds(275);
    digitalWrite(PIN_TX, LOW);

    delay(10);
  }
}
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

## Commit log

2018-10-08 add arduino files
2018-10-08 Net Base not sending OFF commnads to simple 433 devices
2018-10-08 add raspberrypi files
2018-10-13 gestion des sons pour activation/deactivation alarme
2018-10-19 modified actuators
2019-01-01 new generation NetSensor and calibration3V3
2019-01-02 start to implement temperature
2019-01-04 management of temperature and include all data in CMD= in NetBase
2019-01-06 improved voltage measurement and calibration
2019-01-08 include option to calibrate aand set ID at startup
2019-05-10 add keypad and updated domoticz backup
    [keypad3.fcstd]
2019-09-15 add local PIR sensor
2020-04-03 align with current install
2023-05-27 Update NetBase.ino
    debouncing PIR input pin
